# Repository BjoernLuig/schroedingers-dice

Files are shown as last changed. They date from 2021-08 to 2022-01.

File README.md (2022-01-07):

# Schrödingers Dice

A device, which generates truly random numbers using the timestamps of radioactive decay. It uses an <a href="https://github.com/2969773606/GeigerCounter-V1.1">open-source Geiger counter</a> to detect radioactive decays of a small amount of americanuim-241 which is contained in an <a href="https://en.wikipedia.org/wiki/Smoke_detector#Ionization">ionization smoke detector</a>. Each press of the big red button gives a new random number.

This project is highly inspired by <a href="https://www.youtube.com/watch?v=gwIGnATzBTg&list=FLIN6YKhyzmC_FIHTg9GV0EA&index=13&t=27s">The muon-powered, universe-bifurcating, random number machine</a> by <a href="https://www.youtube.com/channel/UCCWeRTgd79JL0ilH0ZywSJA">AlphaPhoenix</a>.

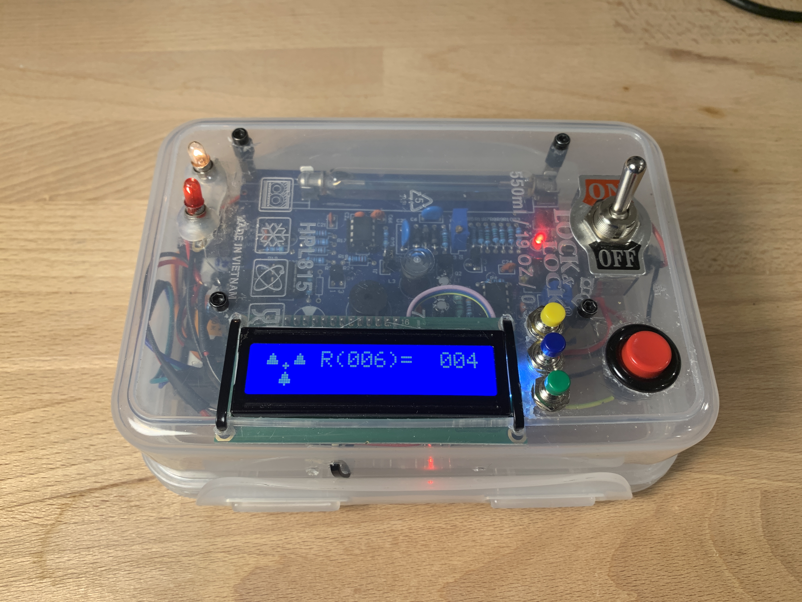
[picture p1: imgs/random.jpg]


## Functionality

### Setting the range for random numbers

The range of the random numbers can be set between 1 and 999 using the green and blue button.

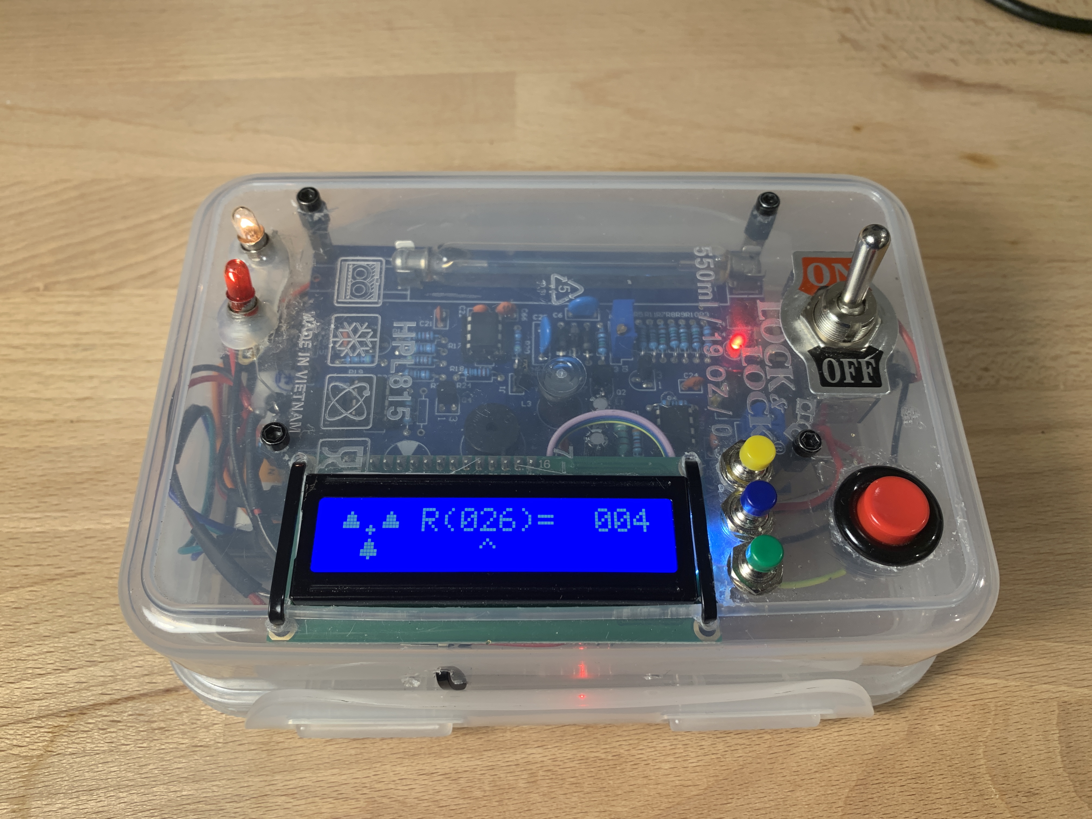
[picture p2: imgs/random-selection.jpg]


### Activity and equivalent dose

It also shows the activity A and equivalent dose E. This mode can be accessed using the yellow button.

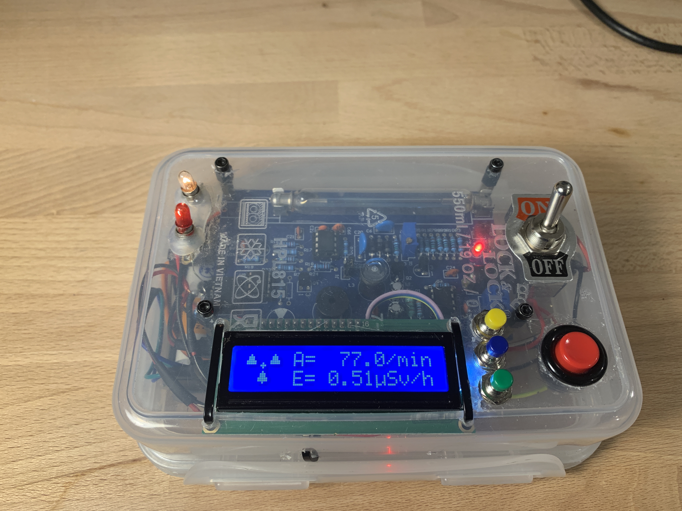
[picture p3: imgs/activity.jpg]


### Battery voltage

The battery voltage U can be displayed by pressing the yellow button twice.

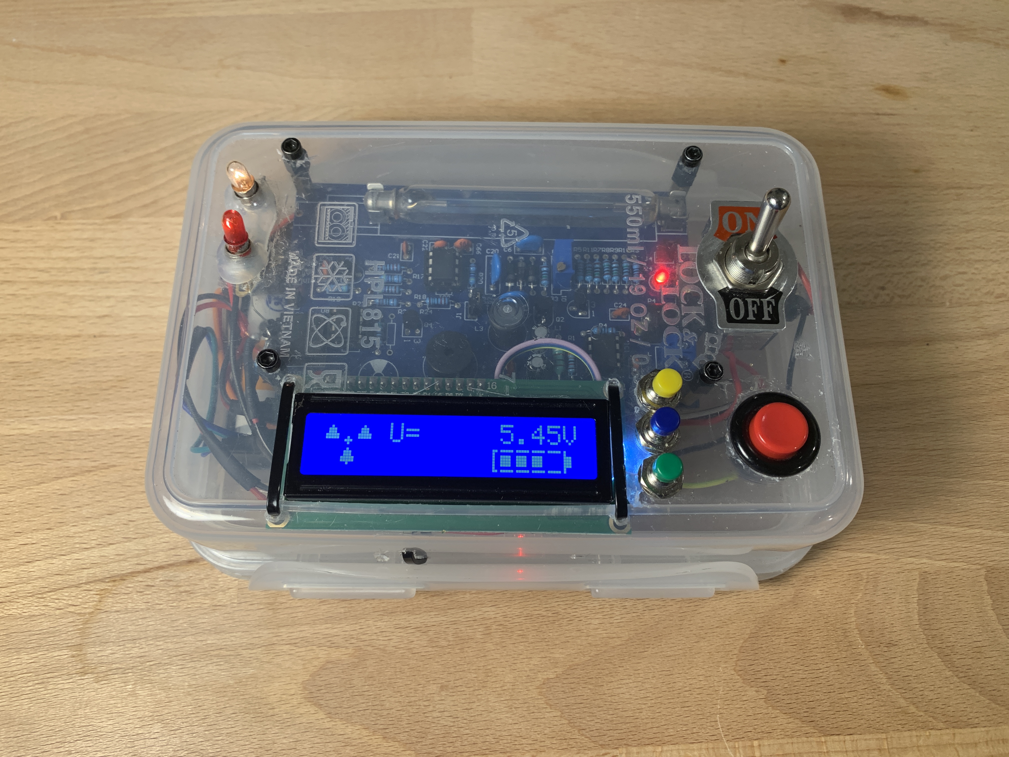
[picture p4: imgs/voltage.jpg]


## How it works

### Physics

Radioactive decays are in contrast to the throw of a dice or computer generated  random numbers truly random. This might not be of any practical use but is philosophically very interesting. (Further information: https://www.youtube.com/watch?v=SxP30euw3-0, https://www.youtube.com/watch?v=ZuvK-od647c)

To detect the radiation of decays (or other radiations) we use a <a href="https://en.wikipedia.org/wiki/Geiger counter">Geiger counter</a> and as a source of radiation an <a href="https://en.wikipedia.org/wiki/Smoke_detector#Ionization">ionization smoke detector</a> containing americanium-241 (see picture below). (Booth can easily be obtained via the internet.)

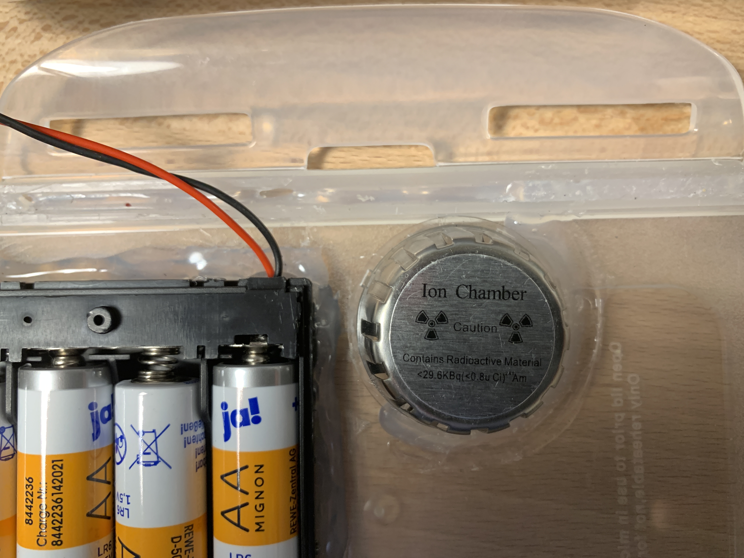
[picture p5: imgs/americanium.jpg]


### Circuit

The components of this project are shown in the fritzing diagram below. An Arduino nano reads the signals of an Geiger counter, runs the code and displays everything on an LCD-display. It also reads the battery voltage using a voltage divider and an analog pin. The detection of a decay can be displayed with a lamp/LED. (In the Photos above, I even added a second lamp directly to the On/Off switch to indicate that the device is on.)

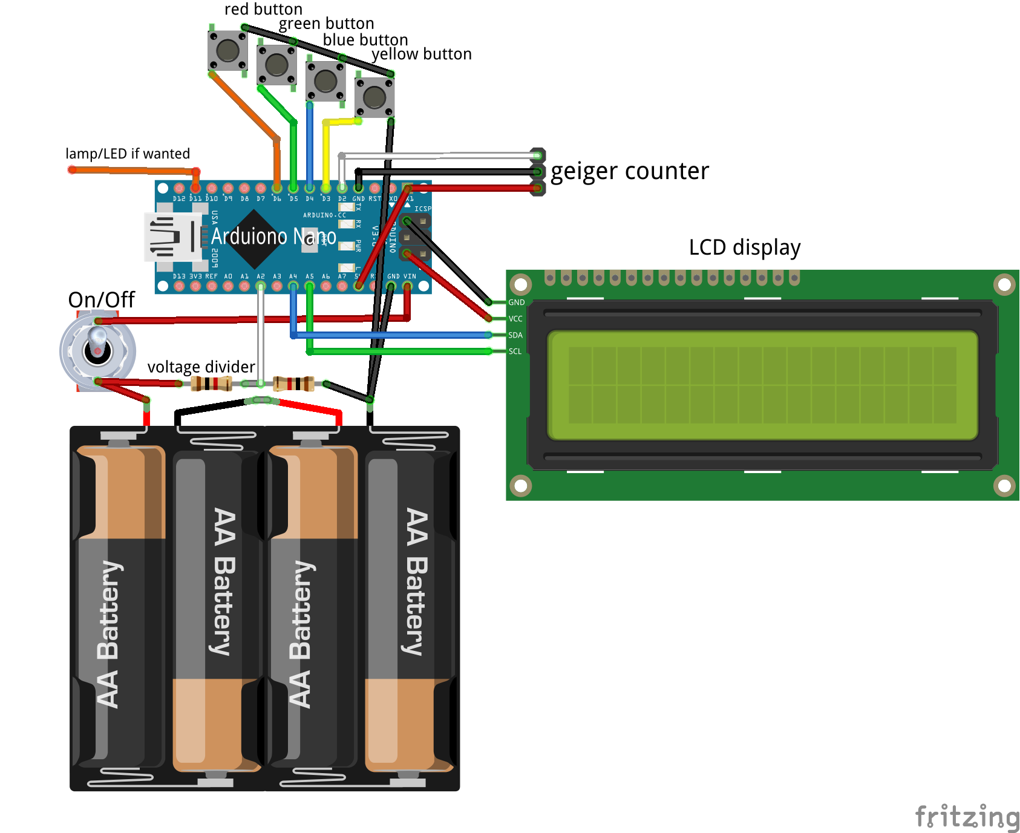
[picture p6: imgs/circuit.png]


The picture below shows all the electronics.

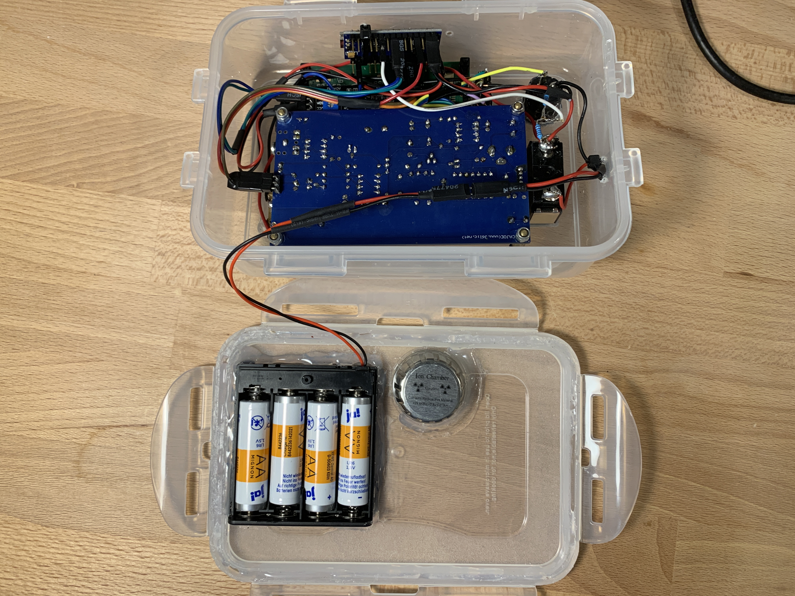
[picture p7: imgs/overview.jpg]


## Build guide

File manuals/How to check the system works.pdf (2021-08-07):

### How to check the system works

step1）Power on the system, use the USB cable connect the system to computer USB Port
step 2）you could hear the beep and see the led flash
how the Geiger Muller Tube works：

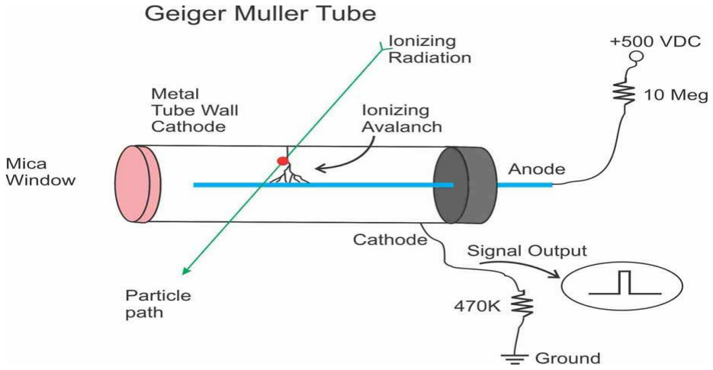
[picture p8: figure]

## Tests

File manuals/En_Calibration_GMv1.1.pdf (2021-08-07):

Calibration:
(the board is calibrated before shipping. If you want to calibrate it again please follow the instruction of calibration)
You need to calibrate the high voltage BEFORE installing Geiger tubes. The HV calibration steps are:
1. Trim R100 potentiometer to approximately 50 ohm when kit power is off.
2. Connect positive Tube Clip to pins (J4) with a jumper wrie.
3. Connect multimeter black probe to any GND point
4. Connect multimeter probe after J2 point

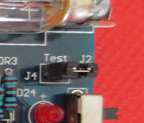
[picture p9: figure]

5. Set your multimeter on 200V DC range.
6. Power up the device (PCB washed and IC555 installed).
7. Adjust voltage with R100 to 6.5V if you use 1M multimeter or adjust the voltage 57V if you use 10M multimeter .Use formula:Vout=Vread*((60M+Rvoltmeter)/Rvoltmeter.)
R100 is the 100Ohm potentiometer.

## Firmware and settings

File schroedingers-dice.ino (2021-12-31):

#include <Wire.h>
#include <LiquidCrystal_I2C.h>

// pins
#define GEIGER_COUNTER 2
#define YELLOW_BUTTON 3
#define BLUE_BUTTON 4
#define GREEN_BUTTON 5
#define RED_BUTTON 6
#define SIGNAL_LAMP 11
#define VOLTAGE A2

// settings
#define COUNTING_INTERVAL 30000 // counting every 30 seconds
#define CONVERSION_INDEX 151    // (counts per minute)/(micro Sv/h)
#define BACKGROUND 25           // backround counts per minutes
#define VOLTAGE_SCALE 0.00851   // (battery voltage)/(sensor voltage) (might not be very accurate)
#define MICROS_FAKTOR 4         // micros() counts in steps of 4 on an arduino nano

// LCD display
LiquidCrystal_I2C lcd(0x27, 16, 2);
byte radioactiveUpperLeft[] = { // see https://maxpromer.github.io/LCD-Character-Creator/ to generate the bytecode
    B00000,
    B00100,
    B01110,
    B01110,
    B11111,
    B11111,
    B00000,
    B00000};
byte radioactiveUpperCenter[] = {
    B00000,
    B00000,
    B00000,
    B00000,
    B00000,
    B00100,
    B01110,
    B00100};
byte radioactiveUpperRight[] = {
    B00000,
    B00100,
    B01110,
    B01110,
    B11111,
    B11111,
    B00000,
    B00000};
byte radioactiveLowerCenter[] = {
    B00100,
    B01110,
    B01110,
    B11111,
    B11111,
    B00100,
    B00000,
    B00000};
byte batteryLeft[] = {
    B00011,
    B00010,
    B00010,
    B00010,
    B00010,
    B00010,
    B00010,
    B00011};
byte batteryCenterFull[] = {
    B11111,
    B00000,
    B11110,
    B11110,
    B11110,
    B11110,
    B00000,
    B11111};
byte batteryCenterEmpty[] = {
    B11111,
    B00000,
    B00000,
    B00000,
    B00000,
    B00000,
    B00000,
    B11111};
byte batteryRight[] = {
    B10000,
    B10000,
    B11100,
    B11100,
    B11100,
    B11100,
    B10000,
    B10000};

// button states
bool yellowButtonState = true; // true means not pressed, false means pressed
bool blueButtonState = true;
bool greenButtonState = true;
bool redButtonState = true;

// modes (0: random number, 1: geiger counter, 2: battery voltage)
short mode = 0;
short nModes = 3;

// mode 0: random number
bool interrupted = false;
bool waitForRandomNumber = false;
short digit = 0;
short randomRangeDigits[] = {6, 0, 0}; // reversed decimal
short randomRange = 6;
short randomNumber = 1;
char randomNumberChars[4];

// mode 1: geiger counter
short count = 0;
unsigned long lastUpdate = 0;
float countsPerMinute = 0.0;
char countsPerMinuteChars[7];
float sievert = 0.0;
char sievertChars[6];

// mode 2: battery voltage
float batteryVoltage = 0;
char batteryVoltageChars[10];
short batterySymbolState;

// will be called on interrupt by particle detection
// do not write to the LCD in this function!!! (loop will break)
void interrupt()
{
  randomNumber = (micros() / MICROS_FAKTOR) % randomRange + 1; // get new random number using division with remainder
  Serial.println("interrupt");
  interrupted = true;
  count++; // increase counts per minutes
  digitalWrite(SIGNAL_LAMP, HIGH);
}

void setup()
{

  // serial
  Serial.begin(9600);
  Serial.println("starting");

  // pins
  pinMode(GEIGER_COUNTER, INPUT);
  pinMode(RED_BUTTON, INPUT_PULLUP);
  pinMode(GREEN_BUTTON, INPUT_PULLUP);
  pinMode(BLUE_BUTTON, INPUT_PULLUP);
  pinMode(YELLOW_BUTTON, INPUT_PULLUP);
  pinMode(SIGNAL_LAMP, OUTPUT);
  attachInterrupt(digitalPinToInterrupt(GEIGER_COUNTER), interrupt, FALLING);

  // start LCD display
  lcd.init();
  lcd.createChar(0, radioactiveUpperLeft);
  lcd.createChar(1, radioactiveUpperCenter);
  lcd.createChar(2, radioactiveUpperRight);
  lcd.createChar(3, radioactiveLowerCenter);
  lcd.createChar(4, batteryLeft);
  lcd.createChar(5, batteryCenterFull);
  lcd.createChar(6, batteryCenterEmpty);
  lcd.createChar(7, batteryRight);
  lcd.backlight();
  lcd.setCursor(0, 0);
  lcd.write(byte(0));
  lcd.write(byte(1));
  lcd.write(byte(2));
  lcd.print(" R(006)=   ? ");
  lcd.setCursor(0, 1);
  lcd.print(" ");
  lcd.write(byte(3));
  lcd.print("              ");
}

void loop()
{

  // yellow button / change mode
  if (yellowButtonState && !digitalRead(YELLOW_BUTTON)) // is pressed but wasn't before
  {
    Serial.println("yellow button");
    mode = (mode + 1) % nModes;
    Serial.println(mode);
    if (mode == 0) // random number
    {
      sprintf(randomNumberChars, "%03d", randomNumber);
      lcd.setCursor(4, 0);
      lcd.print("R(");
      lcd.print((char)(randomRangeDigits[2] + 48)); // digit as char
      lcd.print((char)(randomRangeDigits[1] + 48)); // digit as char
      lcd.print((char)(randomRangeDigits[0] + 48)); // digit as char
      lcd.print(")=  ");
      lcd.print(randomNumberChars);
      lcd.setCursor(4, 1);
      lcd.print("            ");
    }
    else if (mode == 1) // geiger counter
    {
      waitForRandomNumber = false;
      digit = 0;
      dtostrf(countsPerMinute, 6, 1, countsPerMinuteChars);
      dtostrf(sievert, 5, 2, sievertChars);
      lcd.setCursor(4, 0);
      lcd.print("A=");
      lcd.print(countsPerMinuteChars);
      lcd.print("/min");
      lcd.setCursor(4, 1);
      lcd.print("E=");
      lcd.print(sievertChars);
      lcd.print("\xE4Sv/h");
    }
    else if (mode == 2) // battery voltage
    {
      waitForRandomNumber = false;
      digit = 0;
      dtostrf(batteryVoltage, 9, 2, batteryVoltageChars);
      lcd.setCursor(4, 0);
      lcd.print("U=");
      lcd.print(batteryVoltageChars);
      lcd.print("V");
      lcd.setCursor(4, 1);
      lcd.print("      ");
      lcd.write(byte(4));
      lcd.write(byte(5));
      lcd.write(byte(5));
      lcd.write(byte(6));
      lcd.write(byte(6));
      lcd.write(byte(7));
    }
  }
  yellowButtonState = digitalRead(YELLOW_BUTTON);

  // blue button / change selected digit of randomNumberRange
  if (blueButtonState && !digitalRead(BLUE_BUTTON)) // is pressed but wasn't before
  {
    Serial.print("blue button");
    if (digit && (mode == 0))
    {
      randomRangeDigits[digit - 1] = (randomRangeDigits[digit - 1] + 1) % 10;
      randomRange = randomRangeDigits[0] + 10 * randomRangeDigits[1] + 100 * randomRangeDigits[2];
      lcd.setCursor(9 - digit, 0);
      lcd.print((char)(randomRangeDigits[digit - 1] + 48)); // digit as char
    }
    Serial.println((char)(randomRangeDigits[digit - 1] + 48)); // digit as char
  }
  blueButtonState = digitalRead(BLUE_BUTTON);

  // green button / select a digit of randomNumberRange
  if (greenButtonState && !digitalRead(GREEN_BUTTON))
  {
    Serial.print("green button");
    if (mode == 0)
    {
      digit = (digit + 1) % 4;
      if (digit)
      {
        lcd.setCursor(9 - digit, 1);
        lcd.print("^"); // print cursor
        lcd.print(" "); // overwrite old cursor
      }
      else
      {
        lcd.setCursor(6, 1);
        lcd.print("   "); // overwrite old cursor
      }
    }
    Serial.println(digit);
  }
  greenButtonState = digitalRead(GREEN_BUTTON);

  // red button / get new random number
  if (redButtonState && !digitalRead(RED_BUTTON)) // is pressed but wasn't before
  {
    Serial.println("red button");
    digitalWrite(SIGNAL_LAMP, LOW);
    if (mode == 0)
    {
      lcd.setCursor(13, 0);
      lcd.print(" ? ");
      delay(300); // for better visual feedback
    }

    waitForRandomNumber = true; // new number will now be generated by "radioactive interrupt"
  }
  redButtonState = digitalRead(RED_BUTTON);

  // update lcd
  if (mode == 0 && interrupted && waitForRandomNumber)
  { // update mode 0: random number
    sprintf(randomNumberChars, "%03d", randomNumber);
    lcd.setCursor(13, 0);
    lcd.print(randomNumberChars);
    interrupted = false;
    waitForRandomNumber = false;
  }
  else if (mode == 1 && ((millis() - lastUpdate) > COUNTING_INTERVAL))
  { // update mode 1: geiger counter
    countsPerMinute = count * (60000.0 / COUNTING_INTERVAL) - BACKGROUND;
    sievert = countsPerMinute / CONVERSION_INDEX;
    dtostrf(countsPerMinute, 6, 1, countsPerMinuteChars);
    dtostrf(sievert, 5, 2, sievertChars);
    lcd.setCursor(6, 0);
    lcd.print(countsPerMinuteChars);
    lcd.print("/min");
    lcd.setCursor(6, 1);
    lcd.print(sievertChars);
    lcd.print("\xE4Sv/h");
    lastUpdate = millis();
    count = 0;
  }
  else if (mode == 2)
  { // update mode 2: battery voltage
    batteryVoltage = analogRead(VOLTAGE) * VOLTAGE_SCALE;
    dtostrf(batteryVoltage, 9, 2, batteryVoltageChars);
    batterySymbolState = map(batteryVoltage, 4.5, 6.1, 0, 4);
    lcd.setCursor(6, 0);
    lcd.print(batteryVoltageChars);
    lcd.print("V");
    lcd.setCursor(11, 1);
    for (short i = 0; i < 4; i++)
    {
      if (i <= batterySymbolState)
      {
        lcd.write(byte(5));
      }
      else
      {
        lcd.write(byte(6));
      }
    }
  }

  // delay
  delay(100);
}

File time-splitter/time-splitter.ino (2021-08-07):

#include <Wire.h> 
#include <LiquidCrystal_I2C.h>

#define GEIGER_COUNTER 2
#define YELLOW_BUTTON 3
#define BLUE_BUTTON 4
#define GREEN_BUTTON 5
#define RED_BUTTON 6
#define SIGNAL_LAMP 11
#define VOLTAGE A2

LiquidCrystal_I2C lcd(0x27, 16, 2);
byte arrowUp[] = {   // https://maxpromer.github.io/LCD-Character-Creator/
  B00000,
  B00100,
  B01110,
  B10101,
  B00100,
  B00100,
  B00100,
  B00000
};

bool yellowButtonState = true; // false means pressed
bool blueButtonState = true;
bool greenButtonState = true;
bool redButtonState = true;

bool counting = false;
short counterDelay = 20;
//char counterDelayChars[] = "100";
//short counterRange = 1000;
short digit = 0;
short randomRange = 6;
short randomRangeDigits[] = {6, 0, 0};
short randomNumber = 0;
char randomNumberChars[3] = "  1";

void interrupt() {
  Serial.println("interrupt");
  counting = false;
  digitalWrite(SIGNAL_LAMP, HIGH);
}

void setup() {
  Serial.begin(9600);
  Serial.println("starting");
  lcd.init();
  lcd.createChar(0, arrowUp);
  lcd.backlight();
  lcd.setCursor(0, 0);
  lcd.print("Starting");
  pinMode(GEIGER_COUNTER, INPUT);
  pinMode(RED_BUTTON, INPUT_PULLUP);
  pinMode(GREEN_BUTTON, INPUT_PULLUP);
  pinMode(BLUE_BUTTON, INPUT_PULLUP);
  pinMode(YELLOW_BUTTON, INPUT_PULLUP);
  pinMode(SIGNAL_LAMP, OUTPUT);
  attachInterrupt(digitalPinToInterrupt(GEIGER_COUNTER), interrupt, FALLING);
  delay(300);
  lcd.print(".");
  delay(300);
  lcd.print(".");
  delay(300);
  lcd.print(".");
  delay(300);
  lcd.setCursor(0, 0);
  lcd.print("Random(006)=???");
}

void loop() {

  // yellow button
  if(yellowButtonState && ! digitalRead(YELLOW_BUTTON)){
    Serial.println("yellow button");
    yellowButtonState = false;
    // TODO
  }
  else {
    yellowButtonState = digitalRead(YELLOW_BUTTON);
  }

  //blue button
  if(blueButtonState && ! digitalRead(BLUE_BUTTON)) {
    Serial.println("blue button");
    if(digit) {
      randomRangeDigits[digit - 1] = (randomRangeDigits[digit-1] + 1) % 10;
      randomRange = randomRangeDigits[0] + 10 * randomRangeDigits[1] + 100 * randomRangeDigits[2];
      lcd.setCursor(10 - digit, 0);
      lcd.print((char) (randomRangeDigits[digit - 1] + 48));
    }
    blueButtonState = false;
  }
  else {
    blueButtonState = digitalRead(BLUE_BUTTON);
  }

  // green button
  if(greenButtonState && ! digitalRead(GREEN_BUTTON)) {
    Serial.println("green button");
    digit = (digit + 1) % 4;
    if(digit) {
      lcd.setCursor(10 - digit, 1);
      lcd.write(0);
      lcd.print(" ");
    }
    else {
      lcd.setCursor(7, 1);
      lcd.print("   ");
    }
    Serial.println(digit);
    greenButtonState = false;
  }
  else {
    greenButtonState = digitalRead(GREEN_BUTTON);
  }

  // red button
  if(redButtonState && ! digitalRead(RED_BUTTON)) {
    Serial.println("red button");
    digitalWrite(SIGNAL_LAMP, LOW);
    counting = true;
    redButtonState = false;
  }
  else {
    redButtonState = digitalRead(RED_BUTTON);
  }

  // TODO
  //Serial.println(analogRead(VOLTAGE));
  //adjustabe speed, if americanium

  // counting
  delay(counterDelay);
  if(counting) {
    randomNumber = randomNumber % randomRange + 1;
    sprintf(randomNumberChars, "%03d", randomNumber);
    lcd.setCursor(12, 0);
    lcd.print(randomNumberChars);
  }
}

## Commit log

2021-10-10 voltage detection
2021-10-10 corrected calculation of radiatien
    [timeline-splitter.ino]
2021-10-11 voltage bug fix
2021-10-13 battery symbol and bug fixes
    [timeline-splitter.ino]
2021-12-29 readme edit
    [schroedingers-dice.fzz]
2021-12-31 addedfritzing diagramm
    [schroedingers-dice.fzz]
